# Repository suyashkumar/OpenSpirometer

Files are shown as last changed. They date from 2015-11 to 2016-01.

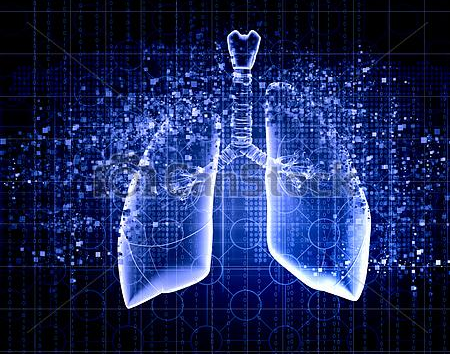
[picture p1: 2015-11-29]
lungs.PNG

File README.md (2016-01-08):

# OpenSpirometer
OpenSpiro is a Bluetooth spirometer that relays data to an Android app on a paired device. The app displays clinical parameters (such as FEV/FVC ratios) over time and in relation to certain tags such as "pollen" (which can be helpful in discovering asthma triggers). All data is automatically stored in the cloud and is accessible via a cloud interface. All electronics, firmware, Android app, server/frontend built by the team can be found here.

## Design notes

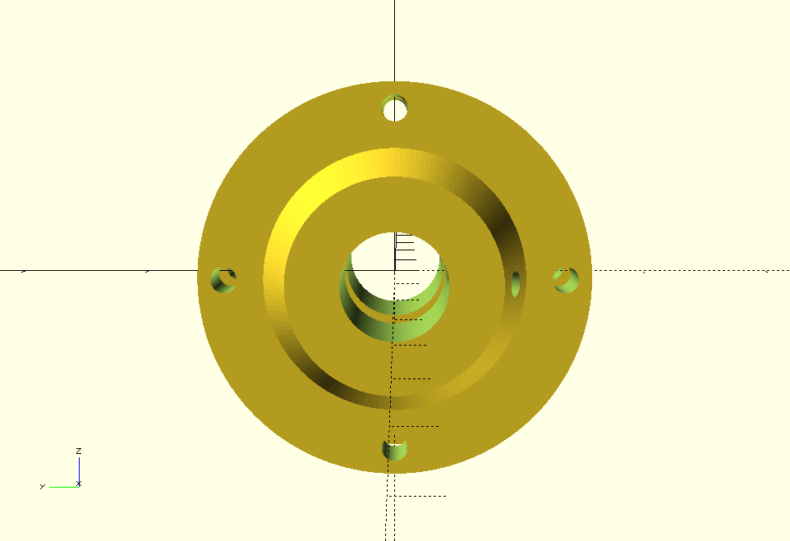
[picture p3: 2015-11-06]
3DModels/SideView.png

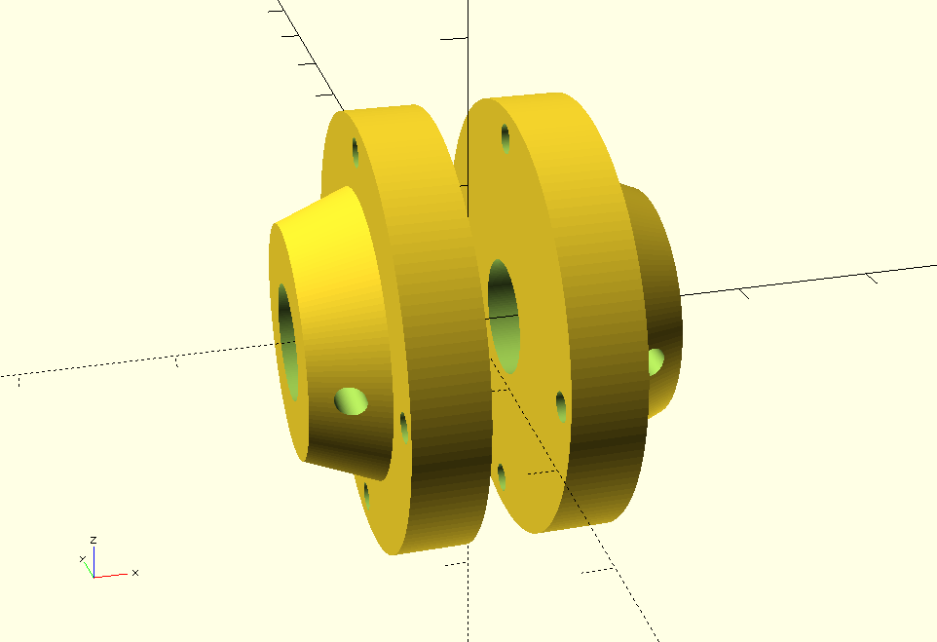
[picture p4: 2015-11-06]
3DModels/pressureChamber_1.png

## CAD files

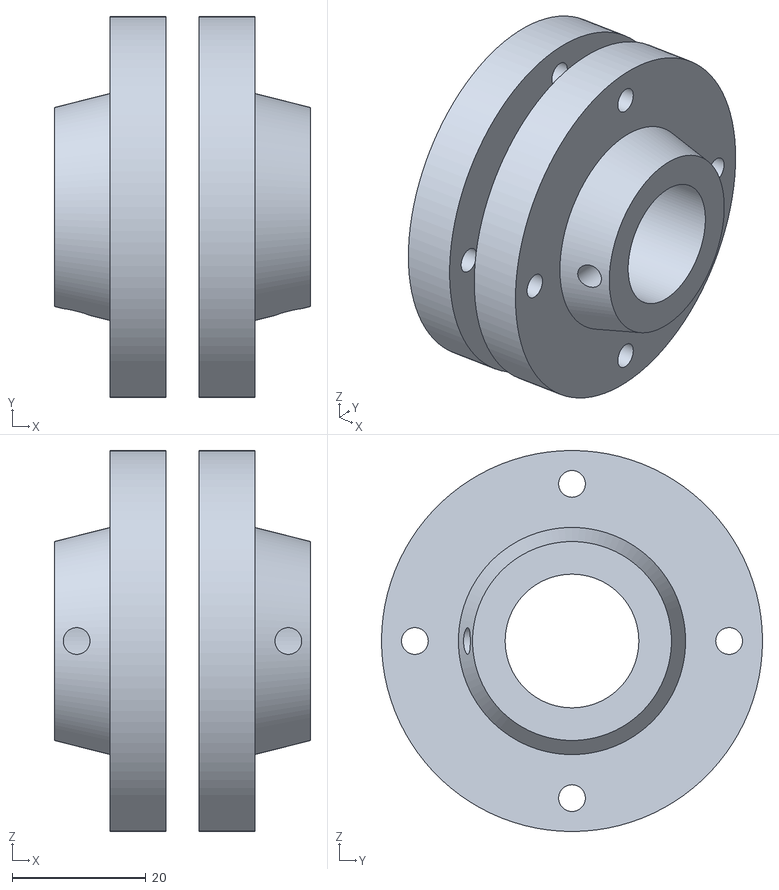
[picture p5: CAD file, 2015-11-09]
3DModels/pressure_chamber_display.stl
38.4 x 57.0 x 57.0

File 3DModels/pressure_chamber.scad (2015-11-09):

//high_quality=true;
bottom_cyl_dia=57.03; // mm
bottom_cyl_height=8.34;
top_cyl_dia=34;
top_cyl_height=30;
screen_cutout=20;
screw_dia=4;
pressure_tube_dia=4;
$fn=50;
//31.2
//29.77
module makeBottom(){
    cylinder(r=bottom_cyl_dia/2, h=bottom_cyl_height);
}

module makeTop(){
    translate([0,0,bottom_cyl_height])cylinder(r1=top_cyl_dia/2, r2=29.77/2, h=bottom_cyl_height);
}

module makeBase(){
    makeBottom();
    makeTop();
}
module cutHoles(){
    screw_translate=(bottom_cyl_dia/2)-5;
    difference(){
        makeBase();
        cylinder(r=screen_cutout/2,h=bottom_cyl_height+top_cyl_height);
        translate([0,screw_translate,0]) cylinder(r=screw_dia/2,h=bottom_cyl_height);
        translate([0,-screw_translate,0]) cylinder(r=screw_dia/2,h=bottom_cyl_height);
        translate([screw_translate,0,0]) cylinder(r=screw_dia/2,h=bottom_cyl_height);
        translate([-screw_translate,0,0]) cylinder(r=screw_dia/2,h=bottom_cyl_height);
        translate([0,0,(bottom_cyl_height+top_cyl_height/2)-10])rotate([90,0,0])cylinder(r=pressure_tube_dia/2,h=30);
    }
}
module makeHalfChamber(){
    cutHoles();
}

module makeShowModel(spaced, spacing=2.5){
    if (spaced){
        translate([spacing,0,0])rotate([0,90,0])makeHalfChamber();
        translate([-spacing,0,0])rotate([0,-90,0])makeHalfChamber();
    }
    else{
        rotate([0,90,0])makeHalfChamber();
        rotate([0,-90,0])makeHalfChamber();
    }
    
}

makeShowModel(spaced=true);
//makeHalfChamber();

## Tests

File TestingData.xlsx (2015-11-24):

Trial | FVC (measured) | % Error | FEV (measured) | Trial | FEV (measured) | FEV % Error
1 | 2.9658 | 1.14 | 2.5563 | 1 | 1.5349 | 2.326666667
2 | 2.9299 | 2.336666667 | 2.1509 | 2 | 1.5204 | 1.36
3 | 2.9908 | 0.3066666667 | 2.0684 | 3 | 1.511 | 0.7333333333
4 | 3.0437 | 1.456666667 | 2.2814 | 4 | 1.5169 | 1.126666667
5 | 2.9897 | 0.3433333333 | 1.7674 | 5 | 1.5091 | 0.6066666667
6 | 3.004 | 0.1333333333 | 1.9328 | 6 | 1.5362 | 2.413333333
7 | 3.0196 | 0.6533333333 | 2.1667 | 7 | 1.5209 | 1.393333333
8 | 2.8353 | 5.49 | 2.5405 | 8 | 1.4976 | 0.16
9 | 3.0273 | 0.91 | 2.1536 | 9 | 1.5338 | 2.253333333
10 | 3.033 | 1.1 | 2.0937 | 10 | 1.5072 | 0.48

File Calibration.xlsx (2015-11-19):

Time (ms) | AnalogRead | Voltage (V) | VdT | sumVdt | k (L/s/V) | Time (ms) | AnalogRead | Voltage (V) | Vdt | sumVdt | k (L/s/V) | Time (ms) | AnalogRead | Voltage (V) | Vdt | sumVdt | k (L/s/V)
0 | 22 | 0.1075268817 | 0.002150537634 | 1.258357771 | 2.38405966 | 0 | 28 | 0.1368523949 | 0.002737047898 | 1.24115347 | 2.417106403 | 0 | 46 | 0.2248289345 | 0.00449657869 | 1.246529814 | 2.406681305
20 | 43 | 0.2101661779 | 0.004203323558 |  |  | 20 | 51 | 0.2492668622 | 0.004985337243 |  |  | 20 | 93 | 0.4545454545 | 0.009090909091
40 | 65 | 0.3176930596 | 0.006353861193 |  |  | 40 | 82 | 0.4007820137 | 0.008015640274 |  |  | 40 | 125 | 0.6109481916 | 0.01221896383
60 | 78 | 0.3812316716 | 0.007624633431 |  |  | 60 | 108 | 0.5278592375 | 0.01055718475 |  |  | 60 | 154 | 0.752688172 | 0.01505376344 |  | k_avg
80 | 93 | 0.4545454545 | 0.009090909091 |  |  | 80 | 134 | 0.6549364614 | 0.01309872923 |  |  | 80 | 178 | 0.8699902248 | 0.0173998045 |  | 2.402615789
100 | 111 | 0.5425219941 | 0.01085043988 |  |  | 100 | 160 | 0.7820136852 | 0.0156402737 |  |  | 100 | 203 | 0.9921798631 | 0.01984359726
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

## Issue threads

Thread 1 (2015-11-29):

Fix x-axis labels of graph

shanafielding, 2015-11-29:
Currently all say 11/24. Change to a time of day for now instead?

suyashkumar, 2015-11-29:
Let's do this for now, though it could be nice to do a simple computation and conditional (are any of them separated by more than a day) to decide to use either the current or the time of day system. Though, for the demo I imagine we'd only be showing the time of day?

suyashkumar, 2015-12-01:
Has this been closed

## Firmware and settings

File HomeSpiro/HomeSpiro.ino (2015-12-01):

  /*
  HomeSpiro.ino.
  A home lung measurement device.
  @author: Suyash Kumar
  @author: Shana Fielding
  @author: Amy Zhao 
  */
  
  #include <Wire.h>  
  #define spiro 0


  int data[400]={};
  int threshold=8; //0.05 V offset from baseline
  int doneLength = 100; //2 seconds of zeros = done
  

  void setup(){
    // set communiation speed
    Serial.begin(9600);   
    pinMode(spiro, OUTPUT);
    
  }

  
  void loop(){
       
     if (Serial.available()>0){
     char incomingByte;
     incomingByte = Serial.read();
     if (incomingByte == '0'){
       
       //automatic offset calculation
      int Vi_sum=0;
      for (int i=0; i<30; i++){ 
        int Vi = analogRead(spiro); //take input from pin 1
        Vi_sum = Vi_sum+Vi;
      }

      float Vi_avg_float = ((float) Vi_sum)/30;
      int Vi_avg = (int) Vi_avg_float;    
      data[400]={};  //reset data array
      measure(Vi_avg);      
      sendData();
    
    }
  }
 
  
}

void measure(int Vi_avg){
    int i=0;
    int zeroCounter = 0;
    boolean breathStarted = false;
    while(i<399){
      int time1 = millis();
      if (zeroCounter>doneLength) break;        //user is done breathing
      int V_in = analogRead(spiro)-Vi_avg;          //auto offset
     
     if (V_in>threshold || breathStarted == true){ //only start counting when value is above threshold
        data[i] = V_in;
        breathStarted = true;
        i++;
     }
     
     if (V_in<threshold && breathStarted == true) zeroCounter++;  //count "0"s after breathStarted
     else zeroCounter=0;               //must be consecutive 
     int time2 = millis();
     int timeElapsed = time2-time1;
     delay(20-timeElapsed);                        //50 Hz sample rate = 20 ms period
    // int testTime = millis();
    // int samplePeriod = testTime-time1;
    // Serial.print(samplePeriod);  
    // Serial.print(", ");
  }
}

void sendData(){
   //Serial.print("[");
    for (int i=0; i<400; i++){
      Serial.print(data[i]);
  //    if(i!=399){
        Serial.print(',');
  //    }
    }
  //  Serial.print("]");
    Serial.println();
    
}

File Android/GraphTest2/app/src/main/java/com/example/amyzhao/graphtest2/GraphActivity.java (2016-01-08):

package com.example.amyzhao.graphtest2;

import android.graphics.Color;
import android.net.ConnectivityManager;
import android.net.NetworkInfo;
import android.support.v7.app.AppCompatActivity;
import android.os.Bundle;
import android.content.Context;
import android.content.Intent;
import android.text.format.DateFormat;
import android.util.Log;
import android.view.Menu;
import android.view.MenuItem;
import android.view.View;
import android.widget.TextView;
import android.widget.Toast;
import com.jjoe64.graphview.GraphView;
import com.jjoe64.graphview.LabelFormatter;
import com.jjoe64.graphview.helper.DateAsXAxisLabelFormatter;
import com.jjoe64.graphview.series.BarGraphSeries;
import com.jjoe64.graphview.series.DataPoint;
import com.jjoe64.graphview.series.DataPointInterface;
import com.jjoe64.graphview.series.LineGraphSeries;
import com.jjoe64.graphview.series.OnDataPointTapListener;
import com.jjoe64.graphview.series.Series;
import com.jjoe64.graphview.Viewport;
import com.jjoe64.graphview.DefaultLabelFormatter;

import java.io.DataOutputStream;
import java.io.IOException;
import java.io.InputStream;
import java.io.OutputStream;
import java.math.BigDecimal;
import java.math.RoundingMode;
import java.net.HttpURLConnection;
import java.net.URL;
import android.os.AsyncTask;
import java.io.BufferedReader;
import java.io.InputStreamReader;

import com.loopj.android.http.*;

import org.json.JSONArray;
import org.json.JSONException;
import org.json.JSONObject;
import org.w3c.dom.Text;

import android.text.format.DateFormat;

import java.text.SimpleDateFormat;
import java.util.*;

public class GraphActivity extends AppCompatActivity {

    String username;
    String URL;
    String content;
    List<Double> FVC;
    List<Double> FEV;
    List<Integer> dates;
    List<List<Double>> dataArray;
    List<List<String>> tagArray;
    private static Context context;
    ArrayList<SpiroData> recData;

    @Override
    protected void onCreate(Bundle savedInstanceState) {
        super.onCreate(savedInstanceState);
        setContentView(R.layout.activity_graph);

        Bundle extra = getIntent().getExtras();
        username = extra.getString("username");
        URL = "http://spiro.suyash.io/api/" + username;
        getDataFromServer();
        recData = new ArrayList<SpiroData>();
        GraphActivity.context = getApplicationContext();
        FEV = new ArrayList<Double>();
        FVC = new ArrayList<Double>();
        dates = new ArrayList<Integer>();
        dataArray = new ArrayList<List<Double>>();
        tagArray = new ArrayList<List<String>>();

    }


    @Override
    public boolean onOptionsItemSelected(MenuItem item) {
        // Handle action bar item clicks here. The action bar will
        // automatically handle clicks on the Home/Up button, so long
        // as you specify a parent activity in AndroidManifest.xml.
        int id = item.getItemId();

        //noinspection SimplifiableIfStatement
        if (id == R.id.action_settings) {
            return true;
        }

        return super.onOptionsItemSelected(item);
    }


    //parse data received from server to send to generateGraphs (will need to add args)
    public void parseDatafromServer(String address) {
        //parse ratios from data
        try {
            JSONArray jArr = new JSONArray(content);
            for (int i=0;i<jArr.length();i++){
                JSONObject currObj = jArr.getJSONObject(i);
                recData.add(new SpiroData(currObj.toString()));

                FEV.add(currObj.getDouble("FEV"));
                FVC.add(currObj.getDouble("FVC"));
                dates.add(Integer.parseInt(currObj.getString("date")));

                JSONObject paramObj = currObj.getJSONObject("params");
                JSONArray tagJSON = paramObj.getJSONArray("tags");

                ArrayList<String> currentTagList = new ArrayList<String>();
                for (int j = 0; j<tagJSON.length(); j++){
                    currentTagList.add(tagJSON.getString(j));
                }
                tagArray.add(currentTagList);

                JSONArray dataJSON = currObj.getJSONArray("data");
            }
        } catch (JSONException e) {
            e.printStackTrace();
        }
        if (FEV.size()!=0) {
            generateGraphs(FEV, FVC);
            updateUI();
        }

    }

    public void updateUI() {
        TextView fev1 = (TextView) findViewById(R.id.fev1Recent);
        TextView fvc = (TextView) findViewById(R.id.fvcRecent);
        //TextView fev1norm = (TextView) findViewById(R.id.fev1Normal);
        //TextView fvcnorm = (TextView) findViewById(R.id.fvcNormal);
        TextView date = (TextView) findViewById(R.id.date);

        Double fev1Val = round(FEV.get(FEV.size()-1), 2);
        Double fvcVal = round(FVC.get(FVC.size()-1), 2);
        String dateVal = dateToString(dates.get(dates.size()-1));

        String fevText = "FEV1: " + Double.toString(fev1Val);
        String fvcText = "FVC: " + Double.toString(fvcVal);
        String fevNormText = "FEV1 (Normal Range): 2.5 - 6.0 L";
        String fvcNormText = "FVC (Normal Range): 3.0 - 7.0 L";
        String dateText = "Date: " + dateVal;

        fev1.setText(fevText + " L");
        fvc.setText(fvcText + " L");
        //fev1norm.setText(fevNormText);
        //fvcnorm.setText(fvcNormText);
        date.setText(dateText);
    }

    public String dateToString(Integer timestamp) {
        int unixSeconds = timestamp;
        Date date = new Date(unixSeconds*1000L); // *1000 is to convert seconds to milliseconds
        SimpleDateFormat sdf = new SimpleDateFormat("yyyy-MM-dd HH:mm:ss z"); // the format of your date
        String formattedDate = sdf.format(date);
        return formattedDate;
    }

    public static double round(double value, int places) {
        if (places < 0) throw new IllegalArgumentException();

        BigDecimal bd = new BigDecimal(value);
        bd = bd.setScale(places, RoundingMode.HALF_UP);
        return bd.doubleValue();
    }

    //Method to get data from server
    public void getDataFromServer() {
        ConnectivityManager connectivityManager = (ConnectivityManager)
                getSystemService(Context.CONNECTIVITY_SERVICE);
        NetworkInfo networkInfo = connectivityManager.getActiveNetworkInfo();
        if (networkInfo != null && networkInfo.isConnected()) {
            new getInfoTask().execute(username);
        } else {
            // error
            System.out.println("No connection.");
        }

    }

    private class getInfoTask extends AsyncTask<String, Void, String> {
        @Override
        protected String doInBackground(String... urls) {

            // params comes from the execute() call: params[0] is the url.
            try {
                if (getInfo()) {
                    return "";
                } else {
                    throw new IOException("error");
                }
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

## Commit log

2015-11-05 Initial Push to Github
    [pressure_chamber.scad]
2015-11-05 added display model stl
    [pressure_chamber.stl]
2015-11-05 Added high resolution display model stl
    [pressure_chamber.scad, pressure_chamber.stl, pressure_chamber_display.stl]
2015-11-05 arduino code
2015-11-06 Added differential pressure tube holes
    [pressure_chamber.scad]
2015-11-06 Updated files and images
    [pressure_chamber.scad, pressure_chamber_display.stl]
2015-11-07 Matched dimensions of part in lab
    [pressure_chamber.scad]
2015-11-08 Updated STL File
    [pressure_chamber.stl]
2015-11-08 Actually updated stl
    [pressure_chamber.stl, pressure_chamber_display.stl]
2015-11-18 adding calibration spreadsheet
    [Calibration.xlsx]
2015-11-19 added framework
2015-11-20 fixed get data methods in GraphActivity
    [GraphActivity.java]
2015-11-21 fixed getData methods in GraphActivity, all activities now pass username to each other
    [GraphActivity.java]
2015-11-22 fixed calibration
    [SampleData.xlsx]
2015-11-23 graph activity now plots with dates as x-axis, auto if given a date array and ratio arraylist
2015-11-24 adding dates
    [TestingData.xlsx]
2015-11-24 calibration changes/testing final data
    [TestingData.xlsx]
2015-11-24 Fixed a bug that has to do with string copying, improving the speed of our application parsing
    [GraphActivity.java]
2015-11-30 Fixed a new user issue
    [GraphActivity.java]
2015-11-30 fixed graphActivity + graph UI
    [GraphActivity.java]
2015-12-01 played around with x-axis of line graph
2015-12-01 changed button colors, updates to arduino
2015-12-02 removed print statements
2015-12-02 removed more print lines from all activities
